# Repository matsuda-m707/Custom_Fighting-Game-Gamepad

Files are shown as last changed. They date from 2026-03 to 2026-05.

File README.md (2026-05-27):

## update
2026-05-28  
[StickBaseパーツ](./STL/StickBase.stl)を調整

# Custom Fighting Game Gamepad
ストリートファイター６用の自作ゲームパッドです。  
スティックの上入力を無効化できるものが欲しくて作りました。  
Raspberry Pi PicoにGP2040-CEをインストールして使います。  
素人設計なので拙い部分が多々あると思います。データを利用する場合は自己責任でお願いします。

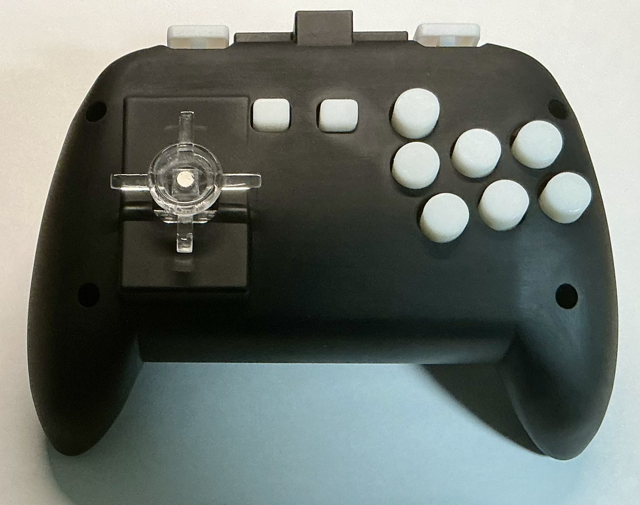
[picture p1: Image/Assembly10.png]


## ライセンス (License)

本プロジェクトのすべてのデータは、以下のライセンスの下で提供されています。

**クリエイティブ・コモンズ 表示 - 非営利 - 継承 4.0 国際 ライセンス (CC BY-NC-SA 4.0)**



You are free to:  
- Share — copy and redistribute the material in any medium or format  
- Adapt — remix, transform, and build upon the material  
The licensor cannot revoke these freedoms as long as you follow the license terms.  
  
Under the following terms:  
- Attribution — You must give appropriate credit, provide a link to the license, and indicate if changes were made. You may do so in any reasonable manner, but not in any way that suggests the licensor endorses you or your use.  
  
- NonCommercial — You may not use the material for commercial purposes.  
  
- ShareAlike — If you remix, transform, or build upon the material, you must distribute your contributions under the same license as the original.  
  
- No additional restrictions — You may not apply legal terms or technological measures that legally restrict others from doing anything the license permits.

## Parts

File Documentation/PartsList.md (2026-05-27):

# 部品表

## 1. 購入するもの

| 部品名 | 型/サイズ | 数量 | 購入先の例 |
| :--- | :--- | :---: | :--- |
| Raspberry Pi Pico | - | 1 | [https://akizukidenshi.com/catalog/g/g118085/] |
| なべ小ねじ | M3 × 8mm | 8 | [https://www.amazon.co.jp/dp/B09SCV6HL5]  |
| なべ小ねじ | M3 × 16mm | 4 | 同上 |
| 六角ナット | M3 | 12 | 同上 |
| キースイッチ | Cherry MX互換 | 17 | [https://shop.yushakobo.jp/products/4278] |
| UBSコネクタ | microBタイプ　オス | 1 | [https://www.amazon.co.jp/dp/B094CC8Z1M] |
| UBSコネクタ | Bタイプ メス | 1 | [https://akizukidenshi.com/catalog/g/g100161/] |
| 導線 | - | 1 | [https://www.amazon.co.jp/dp/B0DV57SHVP] |
| 丸型磁石 | φ5 × 2mm | 2 | [https://www.amazon.co.jp/dp/B0B7BBGM81] |

>  キースイッチについて  
>  軸受けが十字のみの物に対応しています。4個はスティック操作に使うため作動点が1mm前後の物を推奨します。

---

## 2. 発注するもの

このプロジェクト内のデータを使って部品を製造サービスに発注します。  
ここではJLCPCBを想定して推奨する設定がある場合は記載します。

### プリント基板(GerberData)
| ファイル名 | 説明 | 数量 | 備考 |
| :--- | :---: | :---: | :--- |
| Main | メイン基板 |  1 | -  |
| ButtonLR | LRボタン用 |  1 | -  |
| USBConnector | USBコネクタ |  1 | -  |

### 3Dプリント(STL)
| ファイル名 | 説明 | 数量 | 備考 |
| :--- | :---: | :---: | :--- |
| Front | 本体前面 |  1 | -  |
| Back | 本体背面 |  1 | -  |
| Button | 前面ボタン |  7 | -  |
| ButtonLR | LRボタン |  4 | -  |
| ButtonS | Start・Selectボタン |  2 | -  |
| StickBase | スティックパーツ |  1 | 8001Resin or 9000HE Resin  |
| StickAxis | スティックパーツ |  1 | 8001Resin or 9000HE Resin  |
| StickHorizontai | スティックパーツ |  1 | 8001Resin or 9000HE Resin |
| StickVertical | スティックパーツ |  1 | 8001Resin or 9000HE Resin |
| StickHead | スティックパーツ |  1 | 8001Resin or 9000HE Resin |

>  3Dプリントは素材によって同じデータでも寸法にばらつきが出る場合があります。  
>  スティックパーツは他と比べて寸法が重要なので動作を確認した素材を推奨しています。

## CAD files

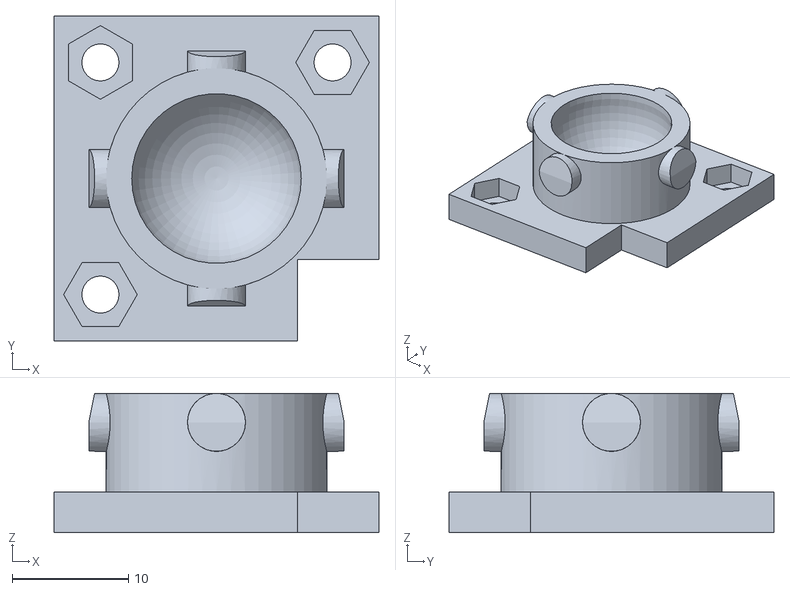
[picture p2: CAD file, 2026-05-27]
STL/StickBase.stl
28.0 x 28.0 x 12.0

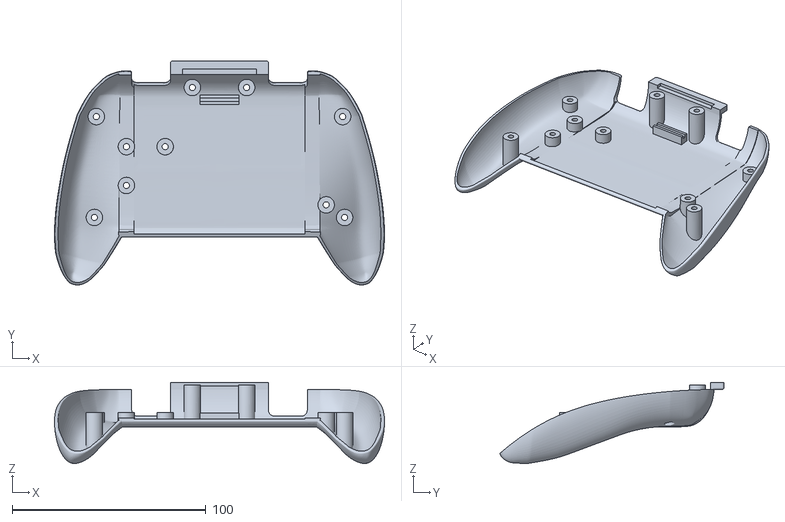
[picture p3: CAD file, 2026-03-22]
STL/Back.stl
170.1 x 115.4 x 41.8

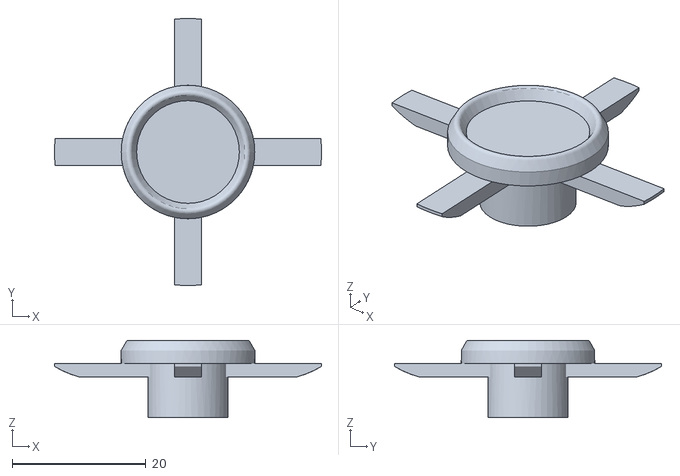
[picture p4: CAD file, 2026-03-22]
STL/StickHead.stl
40.0 x 40.0 x 11.6

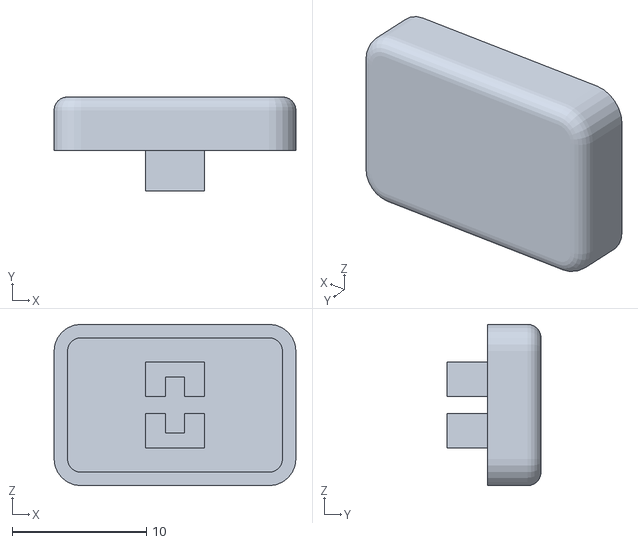
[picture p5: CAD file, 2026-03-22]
STL/ButtonLR.stl
18.0 x 7.00 x 12.0

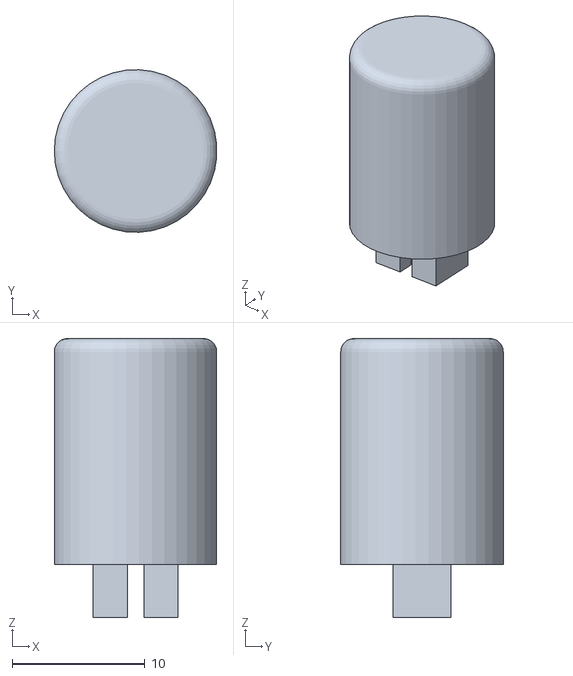
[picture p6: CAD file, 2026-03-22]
STL/Button.stl
12.2 x 12.2 x 21.0

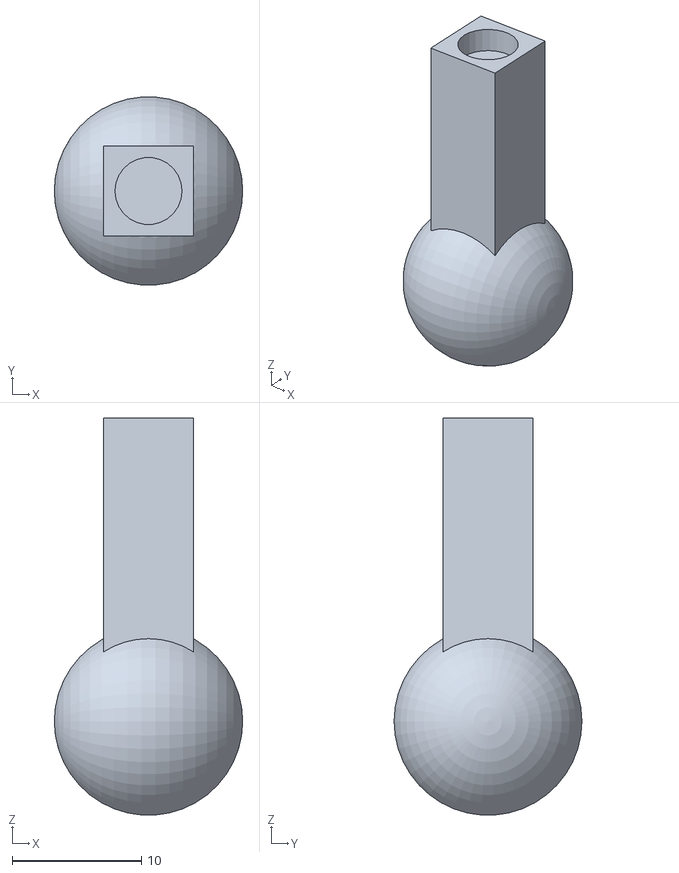
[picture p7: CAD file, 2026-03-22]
STL/StickAxis.stl
14.6 x 14.6 x 30.8

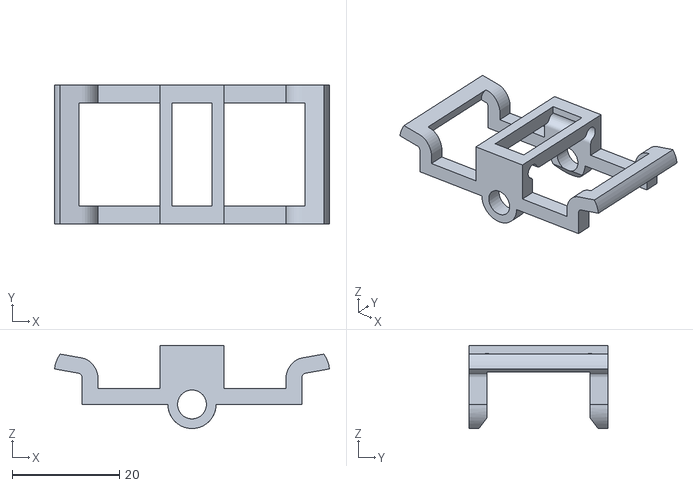
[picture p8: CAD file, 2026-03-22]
STL/StickHorizontal.stl
51.3 x 26.0 x 15.5

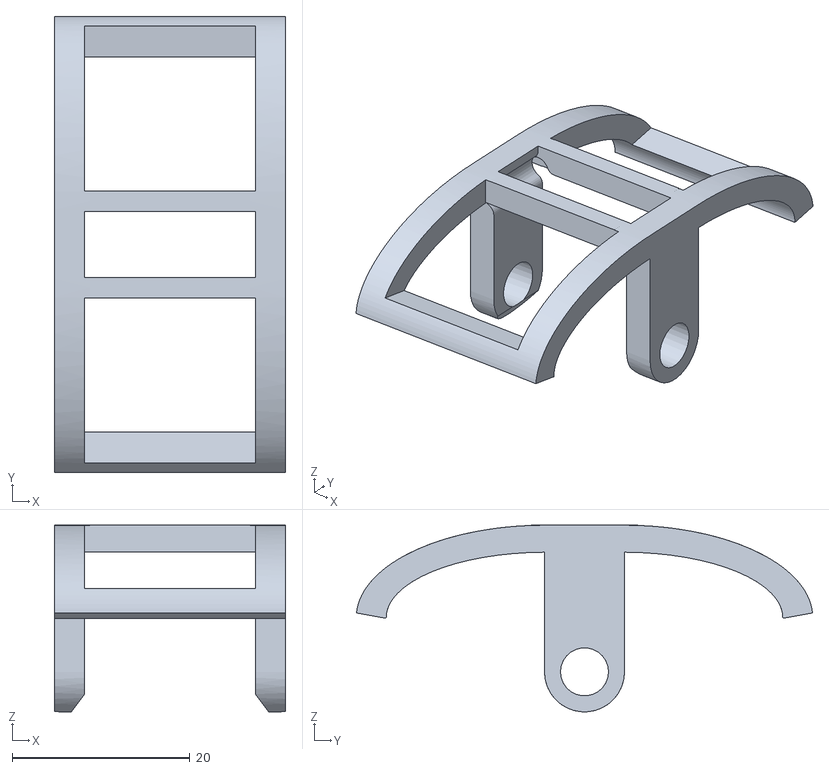
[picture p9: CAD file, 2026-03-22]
STL/StickVertical.stl
26.0 x 51.3 x 21.0

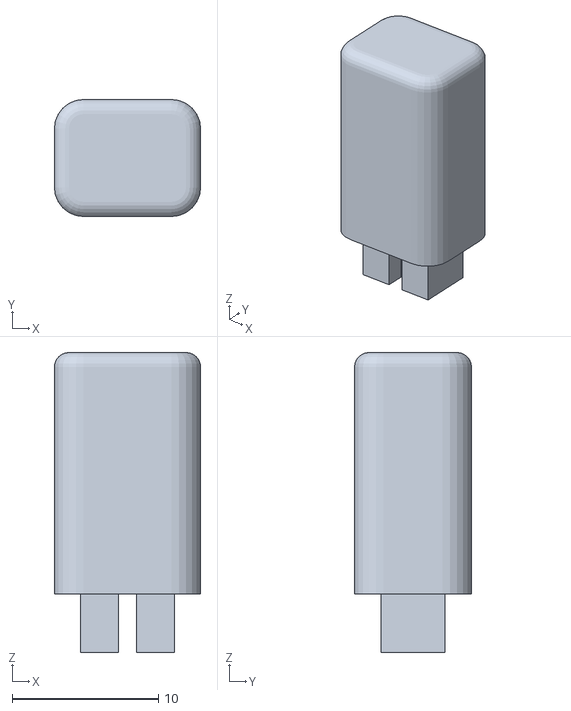
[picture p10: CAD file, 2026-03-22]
STL/ButtonS.stl
10.00 x 8.00 x 20.5

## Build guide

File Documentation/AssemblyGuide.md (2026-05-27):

# 組み立てガイド

## 1. 必要なもの

* はんだ付けセット
* 接着剤
* プラスドライバー
* 各種部品([PartsList](./PartsList.md)参照)

---

## 2. 組み立て手順

### Step 1: 基板（PCB）への部品実装と配線
部品と導線のはんだ付けを行います。  
LRボタン用基板は表裏を間違えやすいです。GNDの印字がない方にスイッチの押す部分がきます。

<div align="center">
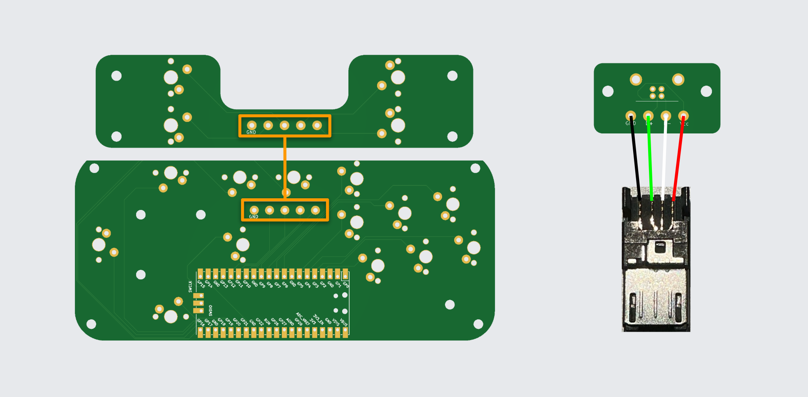
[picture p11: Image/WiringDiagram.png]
配線図
  
  <p>配線図</p> </div>
<div align="center">
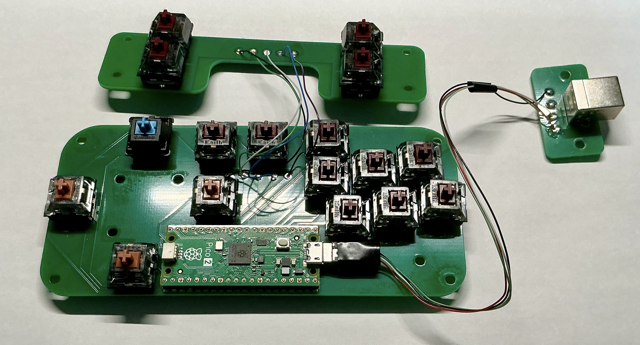
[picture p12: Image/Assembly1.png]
Assembly1
  
  <p>はんだ付けが完了した基板</p> </div>

### Step 2: GP2040-CEのインストール
GP2040-CEをインストールします。すべてのボタンが動くことを確認してピンマッピングの設定を行います。

<div align="center">
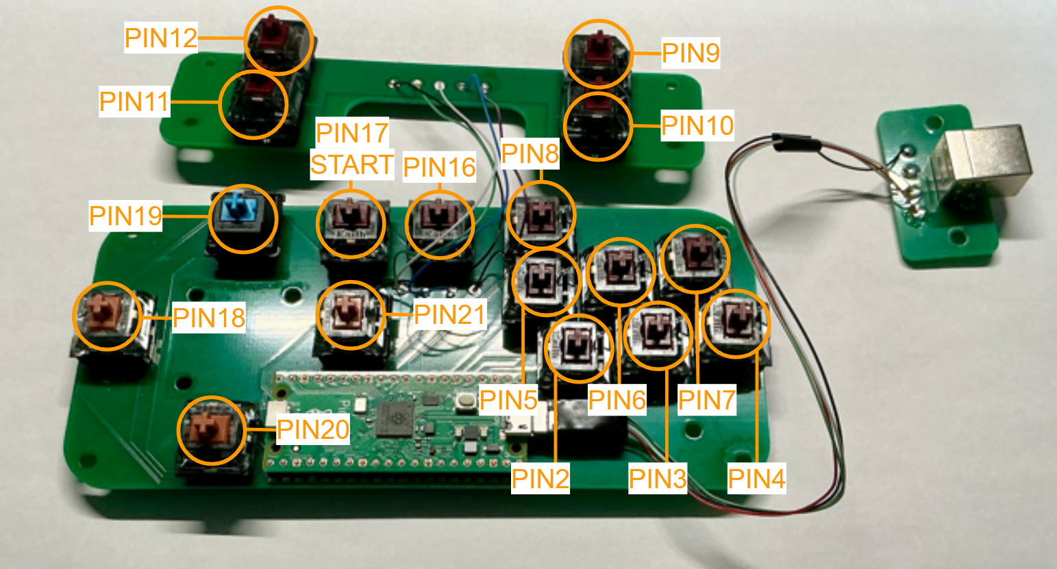
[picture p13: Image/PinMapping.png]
PinMapping
  
  <p>ピンマッピング</p> </div>

### Step 3: スティックの組み立て
①スティックの土台のパーツ(StickBase)にナットを、軸のパーツ(StickAxis)に磁石を接着剤でつけ組み合わせます。  
②スティックの土台の欠けている部分を右下にして、横方向にパーツ(StickHorizontal)をはめ込みます。  
③残りのパーツ(StickVertical)をはめ込みます。  
④スティックの頭のパーツ(StickHead)に軸につけた磁石と引き合うように磁石を接着します。これは今は組み合わせずに本体を組み立てた後にはめ込みます。  
これでスティックは完成です。3Dプリントのばらつきやバリによって滑らかに動かないときはやすり等で調整します。
<div align="center">
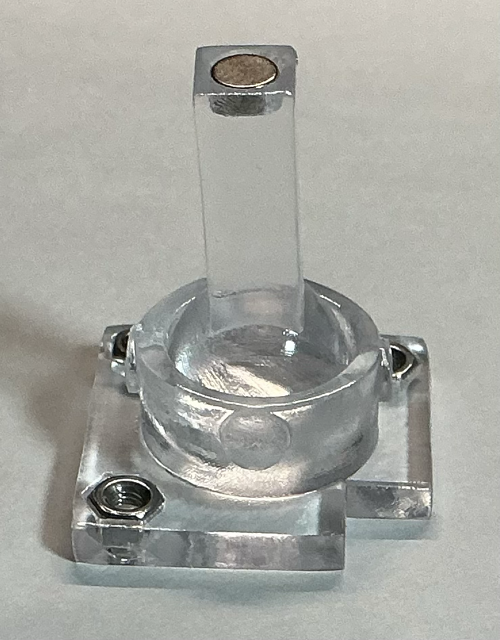
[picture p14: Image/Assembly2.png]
Assembly2
  
  <p>スティック組み立て①</p> </div>

<div align="center">
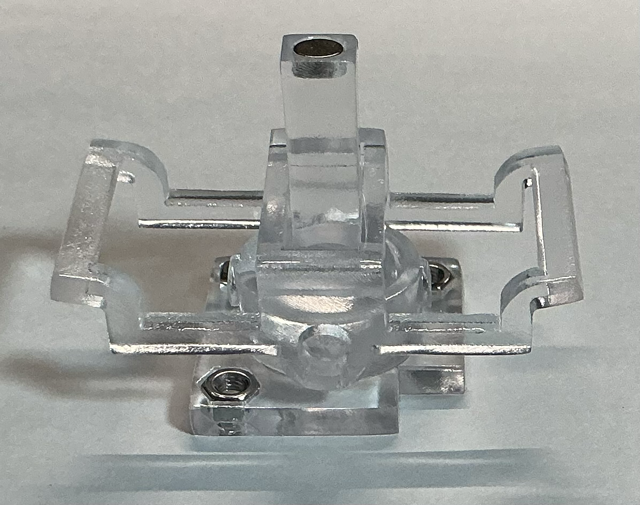
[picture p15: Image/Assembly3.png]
Assembly3
  
  <p>スティック組み立て②</p> </div>

<div align="center">
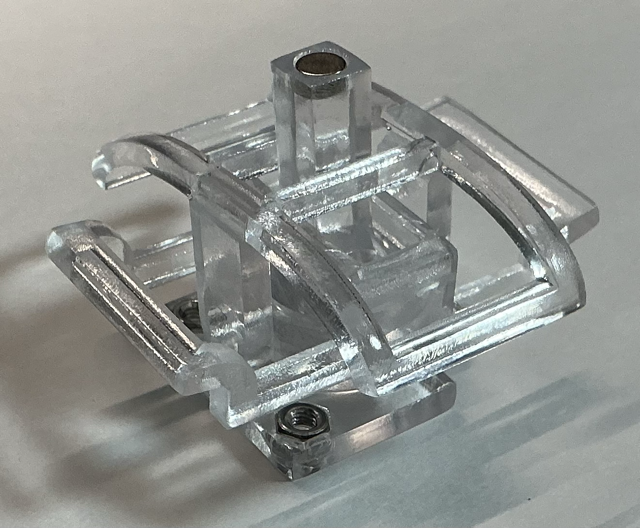
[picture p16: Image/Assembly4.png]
Assembly4
  
  <p>スティック組み立て③</p> </div>

<div align="center">
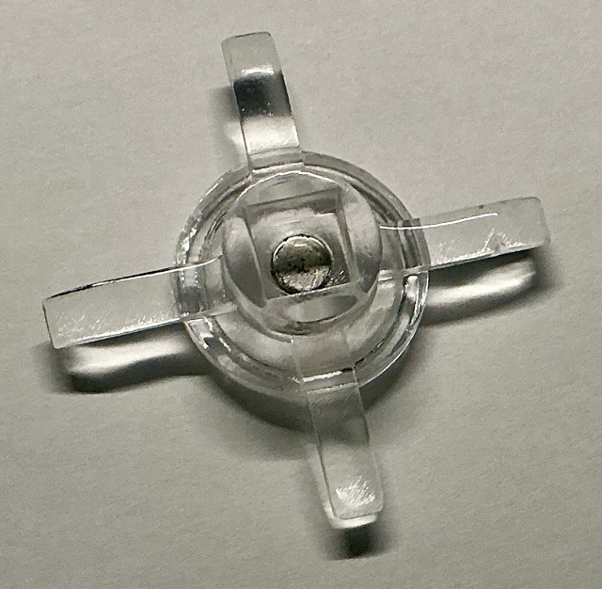
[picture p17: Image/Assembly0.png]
Assembly0
  
  <p>スティック組み立て④</p> </div>

### Step 4: 本体の組み立て
①本体前面(Front)にナットを接着します。  
②本体背面(Back)とはんだ付けした基板を組み合わせてねじとナットで固定します。  
③ボタンパーツをキースイッチにはめ込みます。パーツが大きめなので接着剤かマスキングテープなどシート状のものを噛ませてはめ込むことで固定します。  
④本体背面と前面を組み合わせてねじとナットで固定します。  
⑤端子がついている面から基板をねじで固定します。  
⑥スティックの頭をはめ込んで完成です。
<div align="center">
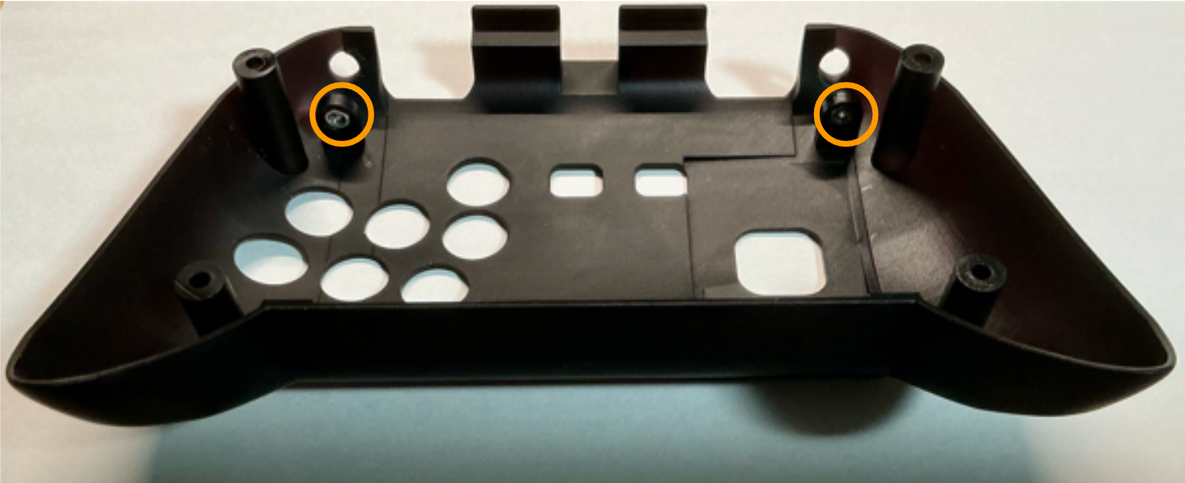
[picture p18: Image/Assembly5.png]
Assembly5
  
  <p>本体組み立て①</p> </div>

<div align="center">
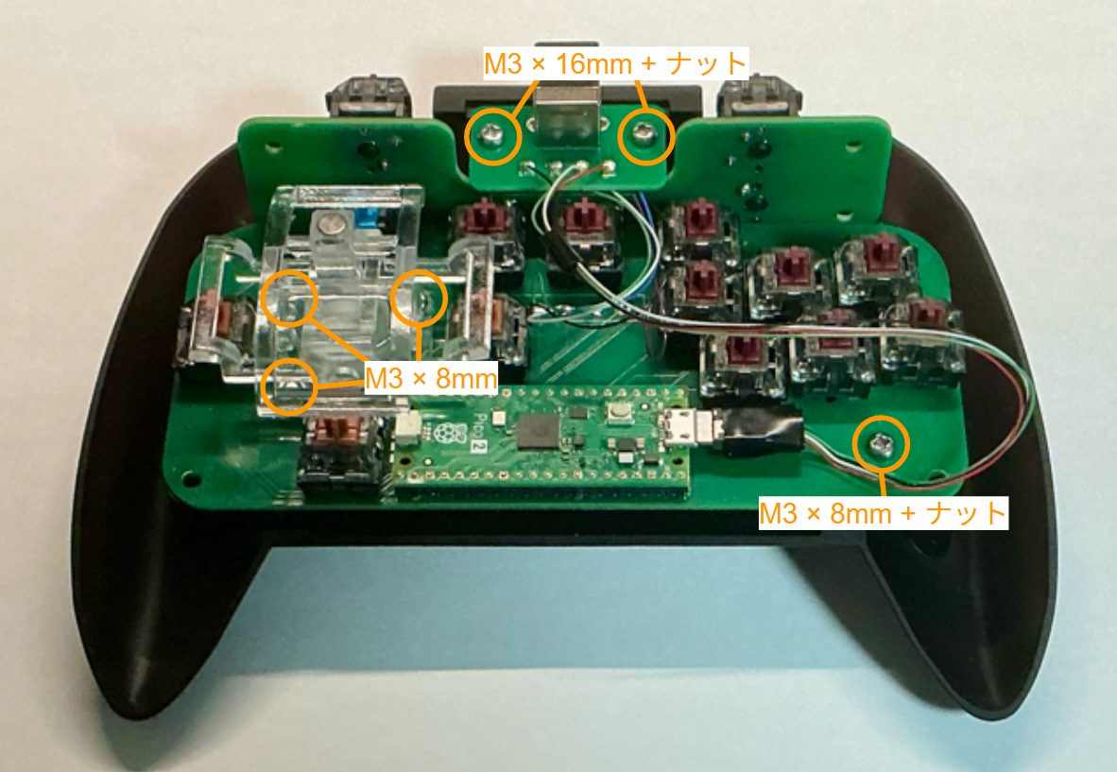
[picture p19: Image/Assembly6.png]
Assembly6
  
  <p>本体組み立て②</p> </div>

<div align="center">
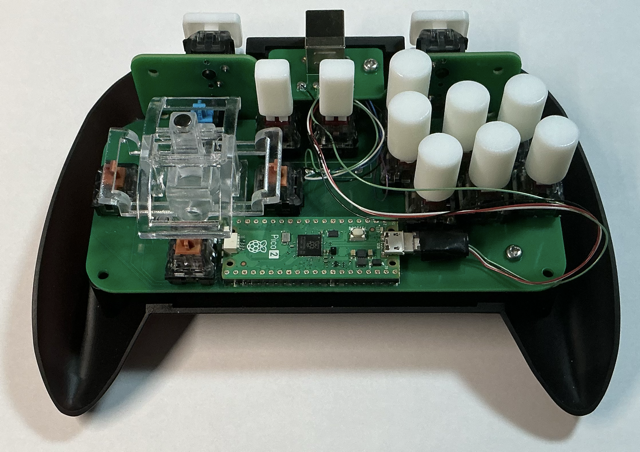
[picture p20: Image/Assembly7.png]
Assembly7
  
  <p>本体組み立て③</p> </div>

<div align="center">
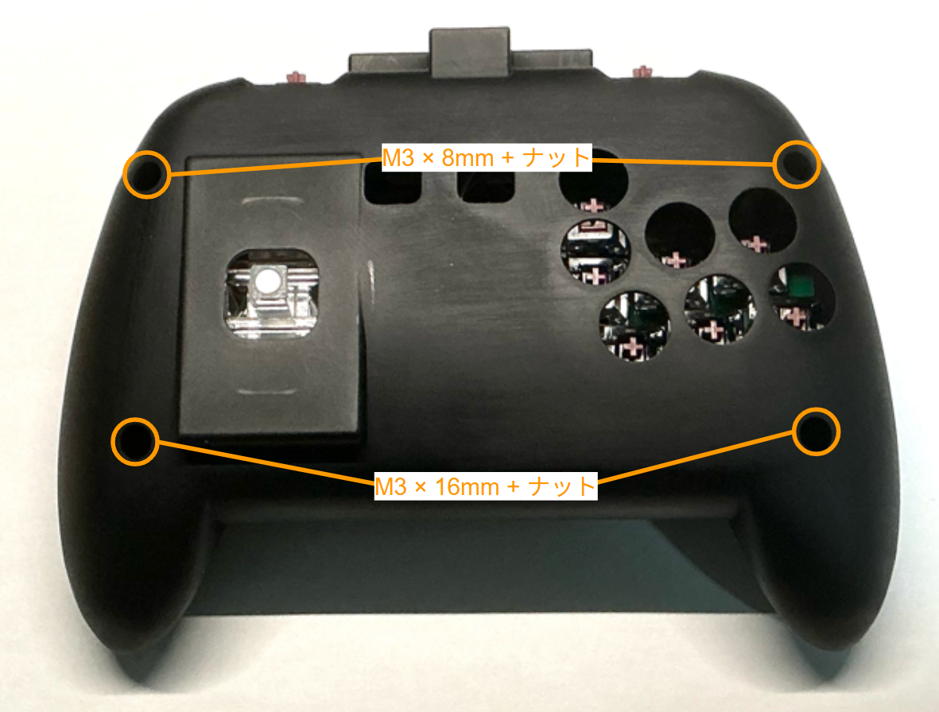
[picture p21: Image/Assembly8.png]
Assembly8
  
  <p>本体組み立て④</p> </div>
  
<div align="center">
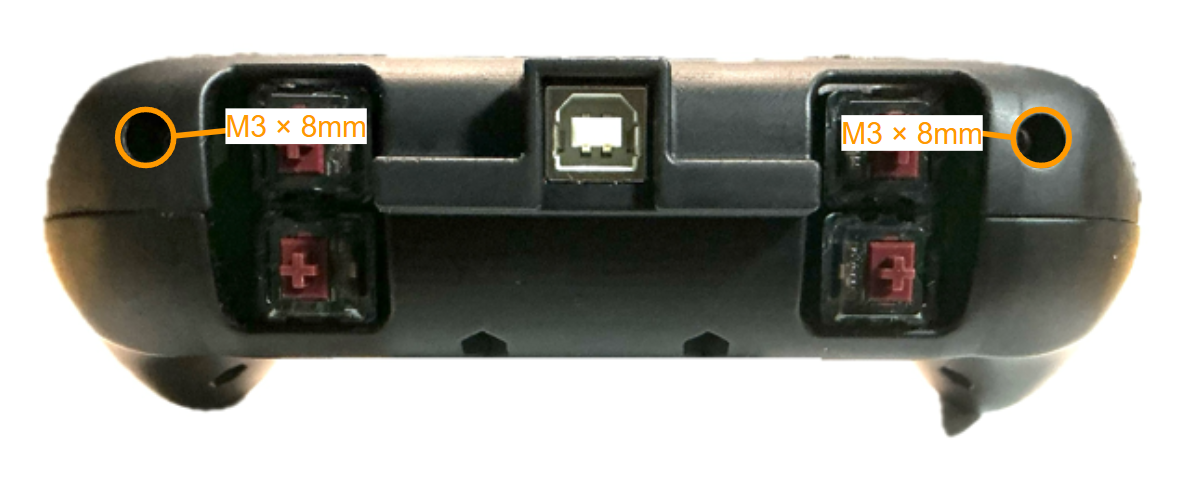
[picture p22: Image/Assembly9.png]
Assembly9
  
  <p>本体組み立て⑤</p> </div>

<div align="center">
  Assembly10
  <p>本体組み立て⑥</p> </div>

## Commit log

2026-03-22 Add data
    [Back.stl, Button.stl, ButtonLR.stl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]
2026-05-27 Update StickBase
    [StickBase.stl]
